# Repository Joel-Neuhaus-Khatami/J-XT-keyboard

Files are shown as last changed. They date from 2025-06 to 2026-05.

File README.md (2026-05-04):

# XT Keyboard Project

NOTE: The RP2040 based design is being replaced with an STM32 variety instead. The readme is thus out of date, however the case files are final
New pcb and firmware will be merged soon.

This repo is for all the files used in designing and manufacturing a mechanical keyboard that I made from scratch.
The keyboard itself is a modified XT layout, which was a very popular layout for 1980's keyboards.

The case is inspired by the IBM Model F77, Cherry G80-0418 and the modern NCR80.
Later angularity and side-bezel thickness was inspired by the Pravetz 16 from the Soviet Union and various NCR G80 varieties, for example the NCR G80-0478.

The PCB is designed Cherry style switch sockets meant for soldering,  all of which are south facing to avoid Cherry profile interference.
The layout is a mix of various layout types, such as the ISO left side 1.25u shift, split right shift, split backspace, which are not changeable.
It does however support stepped caps lock as well as a regular caps lock.
The final PCB iteration is designed with an STM32 chip and currently has only QMK firmware compatibility. This design is confirmed working (from the fact that this README is currently being authored with it).
The PCB was originally designed with using the ATMega32u4 first, then the RP2040, however none of these worked and should be discarded if found in the git history.
Due to the case dimensions, the main intended I/O for the keyboard is a 4-pin Molex Pico EZmate connector and a daughterboard,
in this instance the UDB (Unified Daughterboard) C4. For previous iterations, a full USB type C recepticle + ESD protection diode was added, but these were removed to reduce complexity and assembly time.

## 1. Layout

Capture2

The layout is a mix of the standard HHKB for the Alphanumerical section, XT-esque left side F-row and a 3x5 1U grid inspired by the IBM Model F-77
  
## 2. Schematics

Early visualization of switch matrix (This layout was changed tremendously due to later solutions for multiple layouts)
switch_matrix

Switch matrix translated to Kicad schematics


Full schematics of the board
bilde

Routed pcb
bilde
bilde
bilde

3D render (front)
bilde

3D render (back)
bilde

RP2040, Crystal and Debug pins
bilde

USB Type C Recepticle, ESD Protection Diode and 4-pin Molex Connector
bilde

## 3. Case

Top case w/ plate


Top and Bottom case side profile



Back view including slit for UDB implementation


Inside view of Top case, showing plate top mount + UDB implementation


Inside view of Bottom case


Bottom


## 4. Acknowledgements on PCB design

Given that this project is open source, the shortcomings of the designs and reflections should be acknowledged as its own separate section. The main issue design wise with the PCB is the the 100nF capacitor being on the top rather than the bottom of the PCB. There is no doubt that the capacitor needed to be much closer to RST, however it could have been implemented more elegantly, but this wasn't possible due to time constraints. Also, the board has little/no indicators or tools to perform debugging other than the available BOOT and RST buttons on the back. Indicator lights and available pins for the purposes of debugging would have been useful, and could present a very challenging debugging experience.

To be posted:
Manufactured PCBA and Aluminium case

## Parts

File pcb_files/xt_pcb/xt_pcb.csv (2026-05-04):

# | Reference | Qty | Value | Footprint | DNP
1 | C1, C3 | 2 | 1uF | Capacitor_SMD:C_0402_1005Metric
2 | C2, C5, C6, C7, C8, C9 | 6 | 100nF | Capacitor_SMD:C_0402_1005Metric
3 | C4 | 1 | 4.7uF | Capacitor_SMD:C_0402_1005Metric
4 | D1, D2, D3, D4, D5, D6, D7, D8, D9, D10, D11, D12, D13, D14, D15, D16, D17, D18, D19, D20, D21, D22, D23, D24, D25, D26, D27, D28, D29, D30, D31, D32, D33, D34, D35, D36, D37, D38, D39, D40, D41, D42, D43, D44, D45, D46, D47, D48, D49, D50, D51, D52, D53, D54, D55, D56, D57, D58, D59, D60, D61, D62, D63, D64, D65, D66, D67, D68, D69, D70, D71, D72, D73, D74, D75, D76, D77, D78, D79, D80, D81, D82, D83, D84, D85, D86 | 86 | D | Diode_SMD:D_SOD-123
5 | J1 | 1 | JST | Connector_Molex:Molex_Pico-EZmate_78171-0004_1x04-1MP_P1.20mm_Vertical
6 | R1 | 1 | 10k | Resistor_SMD:R_0402_1005Metric
7 | R2, R3 | 2 | 22Ω | Capacitor_SMD:C_0402_1005Metric
8 | SW1, SW2 | 2 | RST | Button_Switch_SMD:SW_SPST_SKQG_WithoutStem
9 | SW3, SW4, SW5, SW6, SW7, SW8, SW9, SW10, SW11, SW12, SW13, SW18, SW19, SW20, SW21, SW22, SW23, SW24, SW25, SW26, SW29, SW30, SW31, SW32, SW34, SW35, SW36, SW37, SW38, SW39, SW40, SW41, SW42, SW43, SW44, SW45, SW46, SW47, SW48, SW49, SW51, SW52, SW53, SW54, SW55, SW56, SW57, SW58, SW60, SW61, SW62, SW63, SW64, SW65, SW66, SW67, SW68, SW69, SW70, SW71, SW73, SW76, SW77, SW78, SW79, SW80, SW81, SW82, SW83, SW84, SW85, SW86, SW87, SW88, SW89, SW90, SW91 | 77 | SW_Push | PCM_Switch_Keyboard_Cherry_MX:SW_Cherry_MX_PCB_1.00u
10 | SW14, SW74 | 2 | SW_Push | PCM_Switch_Keyboard_Cherry_MX:SW_Cherry_MX_PCB_1.50u
11 | SW15 | 1 | SW_Push | PCM_Switch_Keyboard_Cherry_MX:SW_Cherry_MX_PCB_1.75u
12 | SW16, SW27, SW59 | 3 | SW_Push | PCM_Switch_Keyboard_Cherry_MX:SW_Cherry_MX_PCB_1.25u
13 | SW17, SW75 | 2 | SW_Push | PCM_Switch_Keyboard_Cherry_MX:SW_Cherry_MX_PCB_2.25u
14 | SW28 | 1 | SW_Push | PCM_Mounting_Keyboard_Stabilizer:Stabilizer_Cherry_MX_2.00u
15 | SW33 | 1 | SW_Push | PCM_Mounting_Keyboard_Stabilizer:Stabilizer_Cherry_MX_6.25u
16 | SW50 | 1 | SW_Push | PCM_Switch_Keyboard_Cherry_MX:SW_Cherry_MX_PCB_6.25u
17 | SW72 | 1 | SW_Push | PCM_Switch_Keyboard_Cherry_MX:SW_Cherry_MX_PCB_2.75u
18 | U1 | 1 | STM32F072C8Tx | Package_QFP:LQFP-48_7x7mm_P0.5mm
19 | U2 | 1 | XC6206PxxxMR-Regulator_Linear | Package_TO_SOT_SMD:SOT-23

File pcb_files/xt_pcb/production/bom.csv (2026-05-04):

Designator | Footprint | Quantity | Value | LCSC Part #
C1, C3 | 0402 | 2 | 1uF | C52923
C2 | 0603 | 1 | 100nF | C307331
C4 | 0402 | 1 | 4.7uF | C23733
C5, C6, C7, C8, C9 | 0402 | 5 | 100nF | C307331
D1, D10, D11, D12, D13, D14, D15, D16, D17, D18, D19, D2, D20, D21, D22, D23, D24, D25, D26, D27, D28, D29, D3, D30, D31, D32, D33, D34, D35, D36, D37, D38, D39, D4, D40, D41, D42, D43, D44, D45, D46, D47, D48, D49, D5, D50, D51, D52, D53, D54, D55, D56, D57, D58, D59, D6, D60, D61, D62, D63, D64, D65, D66, D67, D68, D69, D7, D70, D71, D72, D73, D74, D75, D76, D77, D78, D79, D8, D80, D81, D82, D83, D84, D85, D86, D9 | D_SOD-123 | 86 | D
J1 | Molex_Pico-EZmate_78171-0004_1x04-1MP_P1.20mm_Vertical | 1 | JST | C588524
R1 | 0402 | 1 | 10k | C25744
R2, R3 | 0402 | 2 | 22Ω | C25092
SW1, SW2 | SW_SPST_SKQG_WithoutStem | 2 | RST | C139779
SW10, SW11, SW12, SW13, SW18, SW19, SW20, SW21, SW22, SW23, SW24, SW25, SW26, SW29, SW3, SW30, SW31, SW32, SW34, SW35, SW36, SW37, SW38, SW39, SW4, SW40, SW41, SW42, SW43, SW44, SW45, SW46, SW47, SW48, SW49, SW5, SW51, SW52, SW53, SW54, SW55, SW56, SW57, SW58, SW6, SW60, SW61, SW62, SW63, SW64, SW65, SW66, SW67, SW68, SW69, SW7, SW70, SW71, SW73, SW76, SW77, SW78, SW79, SW8, SW80, SW81, SW82, SW83, SW84, SW85, SW86, SW87, SW88, SW89, SW9, SW90, SW91 | SW_Cherry_MX_PCB_1.00u | 77 | SW_Push
SW14, SW74 | SW_Cherry_MX_PCB_1.50u | 2 | SW_Push
SW15 | SW_Cherry_MX_PCB_1.75u | 1 | SW_Push
SW16, SW17, SW27, SW59 | SW_Cherry_MX_PCB_1.25u | 4 | SW_Push
SW28 | Stabilizer_Cherry_MX_2.00u | 1 | SW_Push
SW33 | Stabilizer_Cherry_MX_6.25u | 1 | SW_Push
SW50 | SW_Cherry_MX_PCB_6.25u | 1 | SW_Push
SW72 | SW_Cherry_MX_Plate_1.75u | 1 | SW_Push
SW75 | SW_Cherry_MX_PCB_2.25u | 1 | SW_Push
U1 | LQFP-48_7x7mm_P0.5mm | 1 | STM32F072C8Tx | C80488
U2 | SOT-23 | 1 | XC6206PxxxMR-Regulator_Linear | C5446

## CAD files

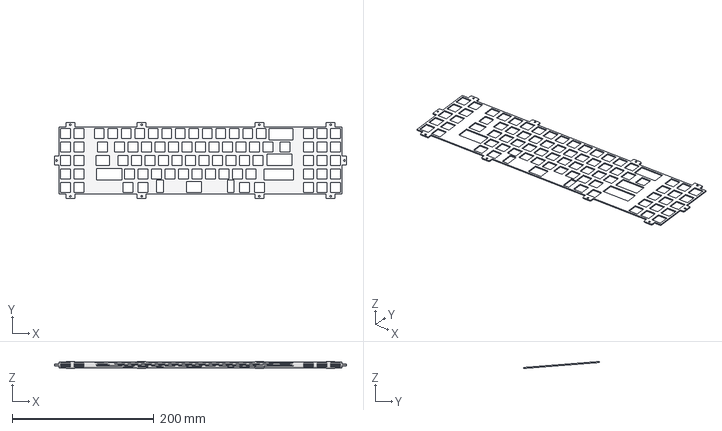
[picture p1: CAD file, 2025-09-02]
case_files/plate.step
412.0 x 107.1 x 9.91 mm

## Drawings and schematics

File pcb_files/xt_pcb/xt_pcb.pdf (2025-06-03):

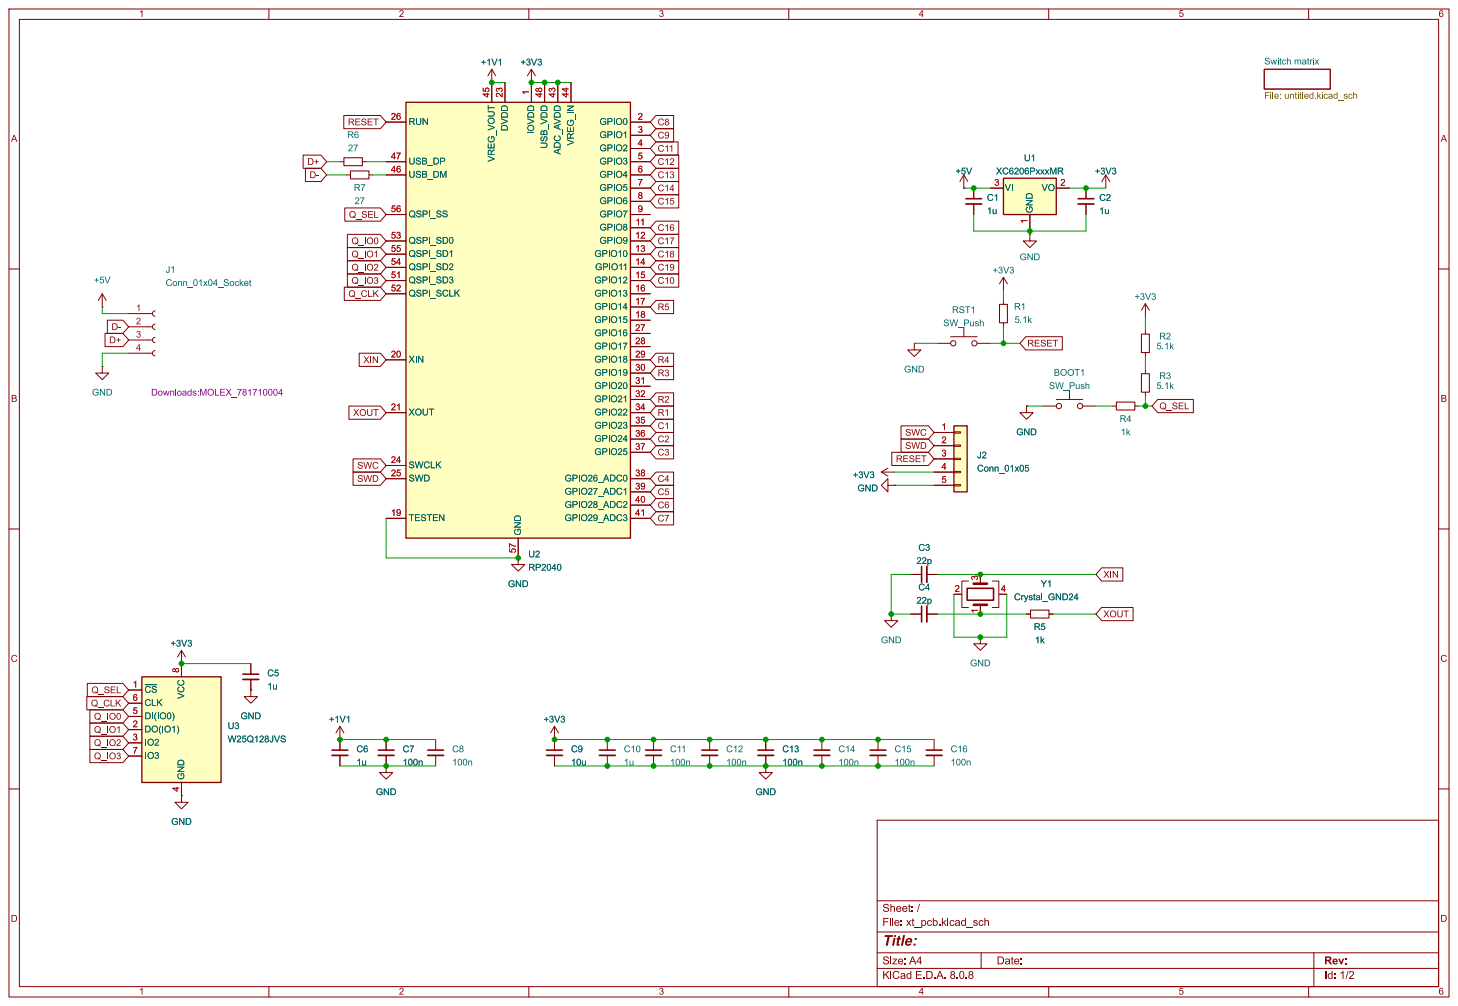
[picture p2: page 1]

Switch matrix File: untitled.kicad_sch +3V3 R2

Id: 1/2 Title: File: xt_pcb.kicad_sch Sheet: /

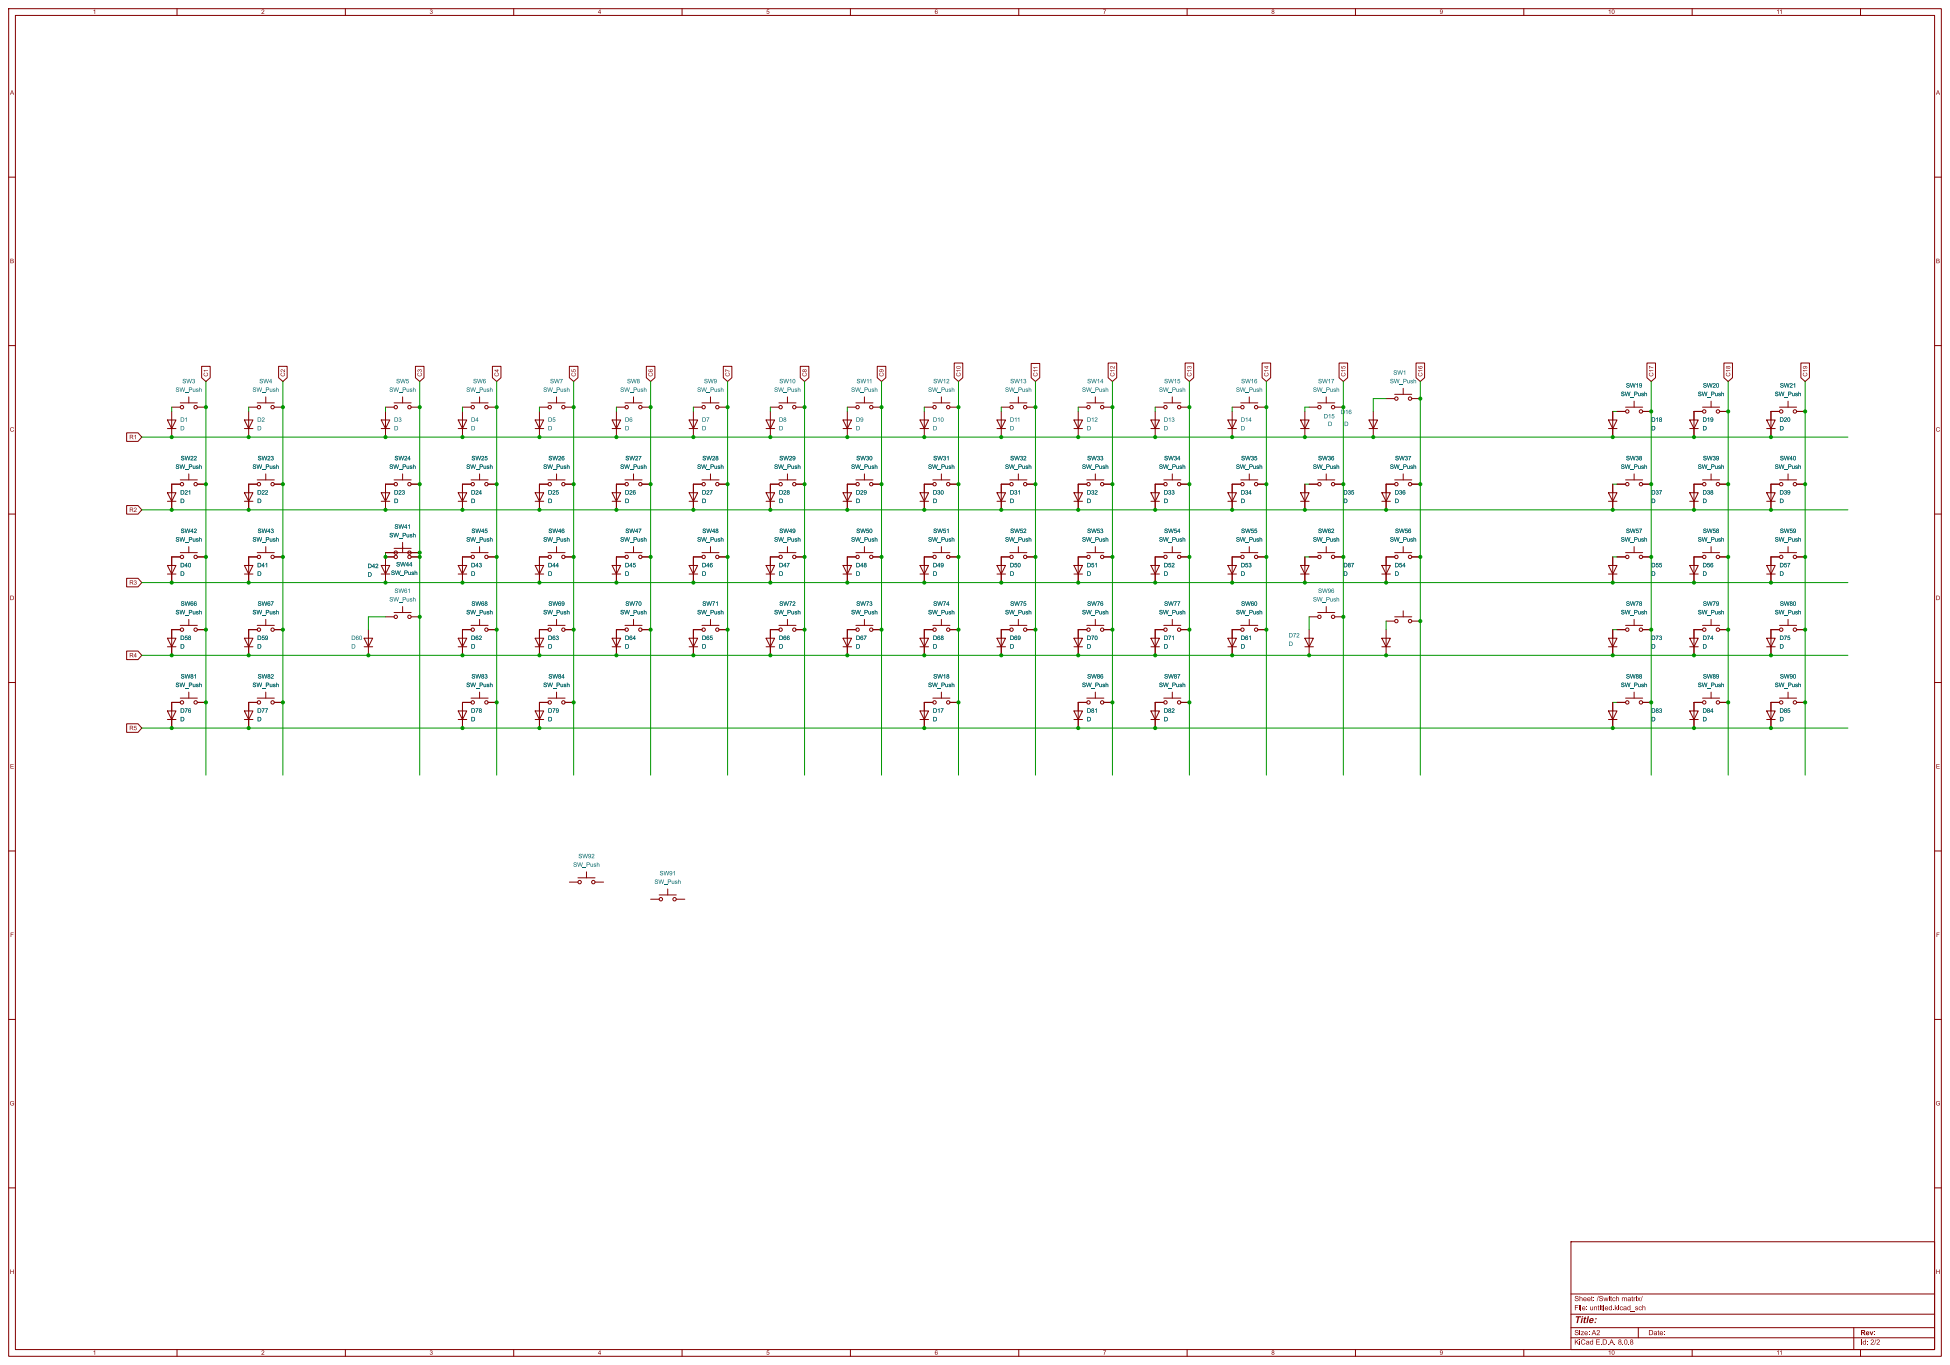
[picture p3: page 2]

Id: 2/2 Title: File: untitled.kicad_sch Sheet: /Switch matrix/

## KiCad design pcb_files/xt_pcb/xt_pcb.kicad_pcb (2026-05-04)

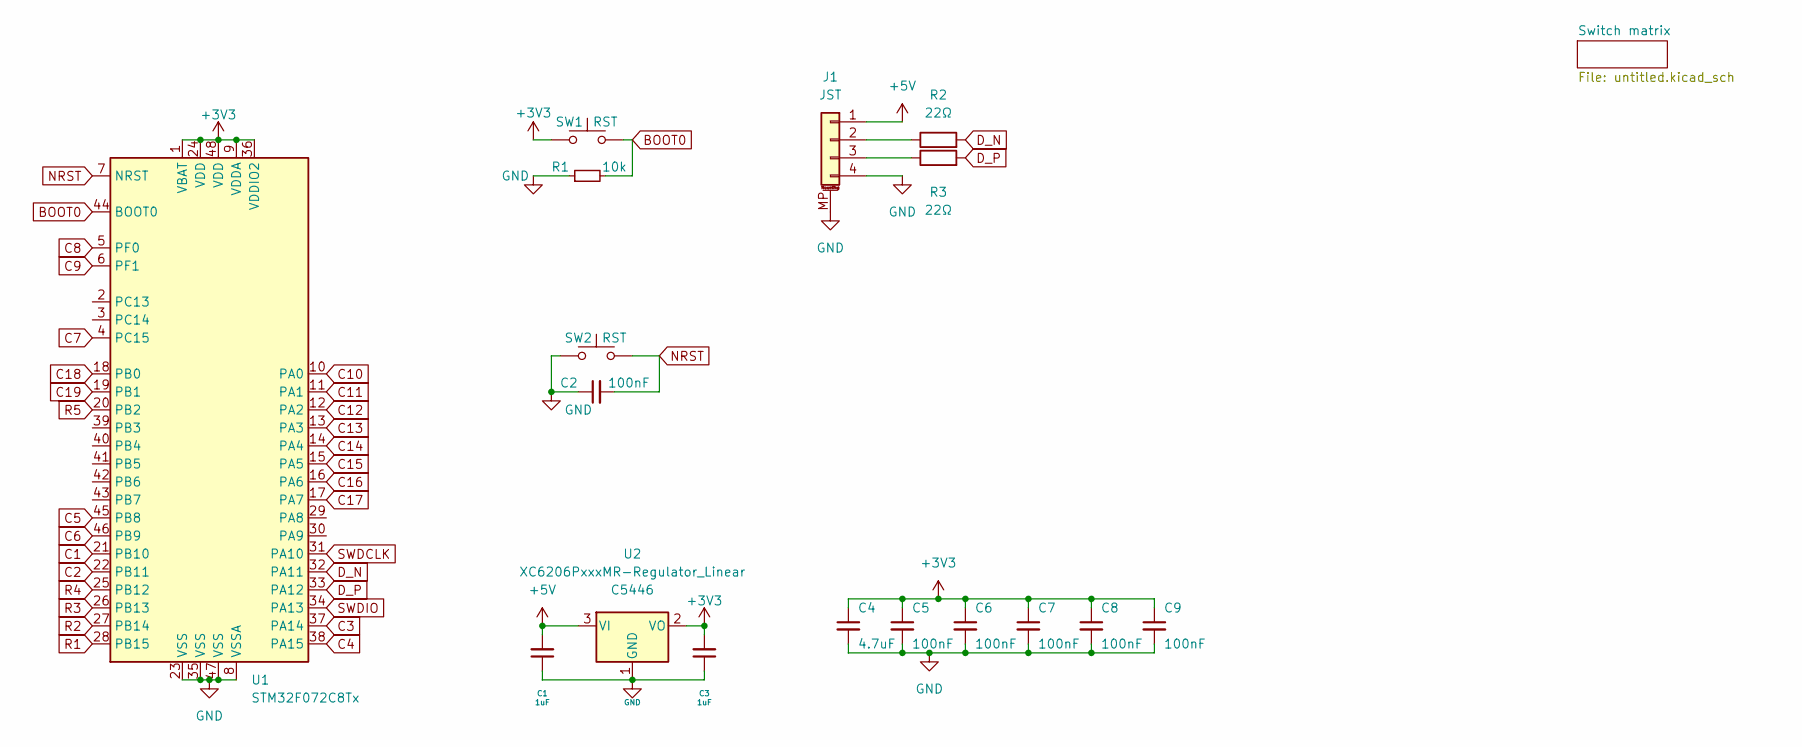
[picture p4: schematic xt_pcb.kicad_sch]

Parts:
C1, C3: 1uF; C_0402_1005Metric; LCSC C52923
C2: 100nF; C_0603_1608Metric_Pad1.08x0.95mm_HandSolder; LCSC C307331
C4: 4.7uF; C_0402_1005Metric; LCSC C23733
C5, C6, C7, C8, C9: 100nF; C_0402_1005Metric; LCSC C307331
J1: JST; Molex_Pico-EZmate_78171-0004_1x04-1MP_P1.20mm_Vertical; LCSC C588524
R1: 10k; R_0402_1005Metric; LCSC C25744
R2, R3: 22Ω; C_0402_1005Metric; LCSC C25092
SW1, SW2: RST; SW_SPST_SKQG_WithoutStem; LCSC C139779
U1: STM32F072C8Tx; LQFP-48_7x7mm_P0.5mm; LCSC C80488
U2: XC6206PxxxMR-Regulator_Linear; SOT-23; LCSC C5446

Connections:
+3V3: C3.2, C4.1, C5.1, C6.1, C7.1, C8.1, C9.1, SW1.1, U1.1 (VBAT), U1.9 (VDDA), U1.24 (VDD), U1.36 (VDDIO2), U1.48 (VDD), U2.2 (VO)
+5V: C1.2, J1.1, U2.3 (VI)
BOOT0: R1.2, SW1.2, U1.44 (BOOT0)
C1: U1.21 (PB10); also elsewhere on the board
C2: U1.22 (PB11); also elsewhere on the board
C3: U1.37 (PA14); also elsewhere on the board
C4: U1.38 (PA15); also elsewhere on the board
C5: U1.45 (PB8); also elsewhere on the board
C6: U1.46 (PB9); also elsewhere on the board
C7: U1.4 (PC15); also elsewhere on the board
C8: U1.5 (PF0); also elsewhere on the board
C9: U1.6 (PF1); also elsewhere on the board
C10: U1.10 (PA0); also elsewhere on the board
C11: U1.11 (PA1); also elsewhere on the board
C12: U1.12 (PA2); also elsewhere on the board
C13: U1.13 (PA3); also elsewhere on the board
C14: U1.14 (PA4); also elsewhere on the board
C15: U1.15 (PA5); also elsewhere on the board
C16: U1.16 (PA6); also elsewhere on the board
C17: U1.17 (PA7); also elsewhere on the board
C18: U1.18 (PB0); also elsewhere on the board
C19: U1.19 (PB1); also elsewhere on the board
D_N: R2.2, U1.32 (PA11)
D_P: R3.2, U1.33 (PA12)
GND: C1.1, C2.1, C3.1, C4.2, C5.2, C6.2, C7.2, C8.2, C9.2, J1.4, J1.MP (MountPin), R1.1, SW2.1, U1.8 (VSSA), U1.23 (VSS), U1.35 (VSS), U1.47 (VSS), U2.1 (GND)
NRST: C2.2, SW2.2, U1.7 (NRST)
unnamed: J1.2, R2.1
unnamed: J1.3, R3.1
R1: U1.28 (PB15); also elsewhere on the board
R2: U1.27 (PB14); also elsewhere on the board
R3: U1.26 (PB13); also elsewhere on the board
R4: U1.25 (PB12); also elsewhere on the board
R5: U1.20 (PB2); also elsewhere on the board
SWDCLK: U1.31 (PA10)
SWDIO: U1.34 (PA13)

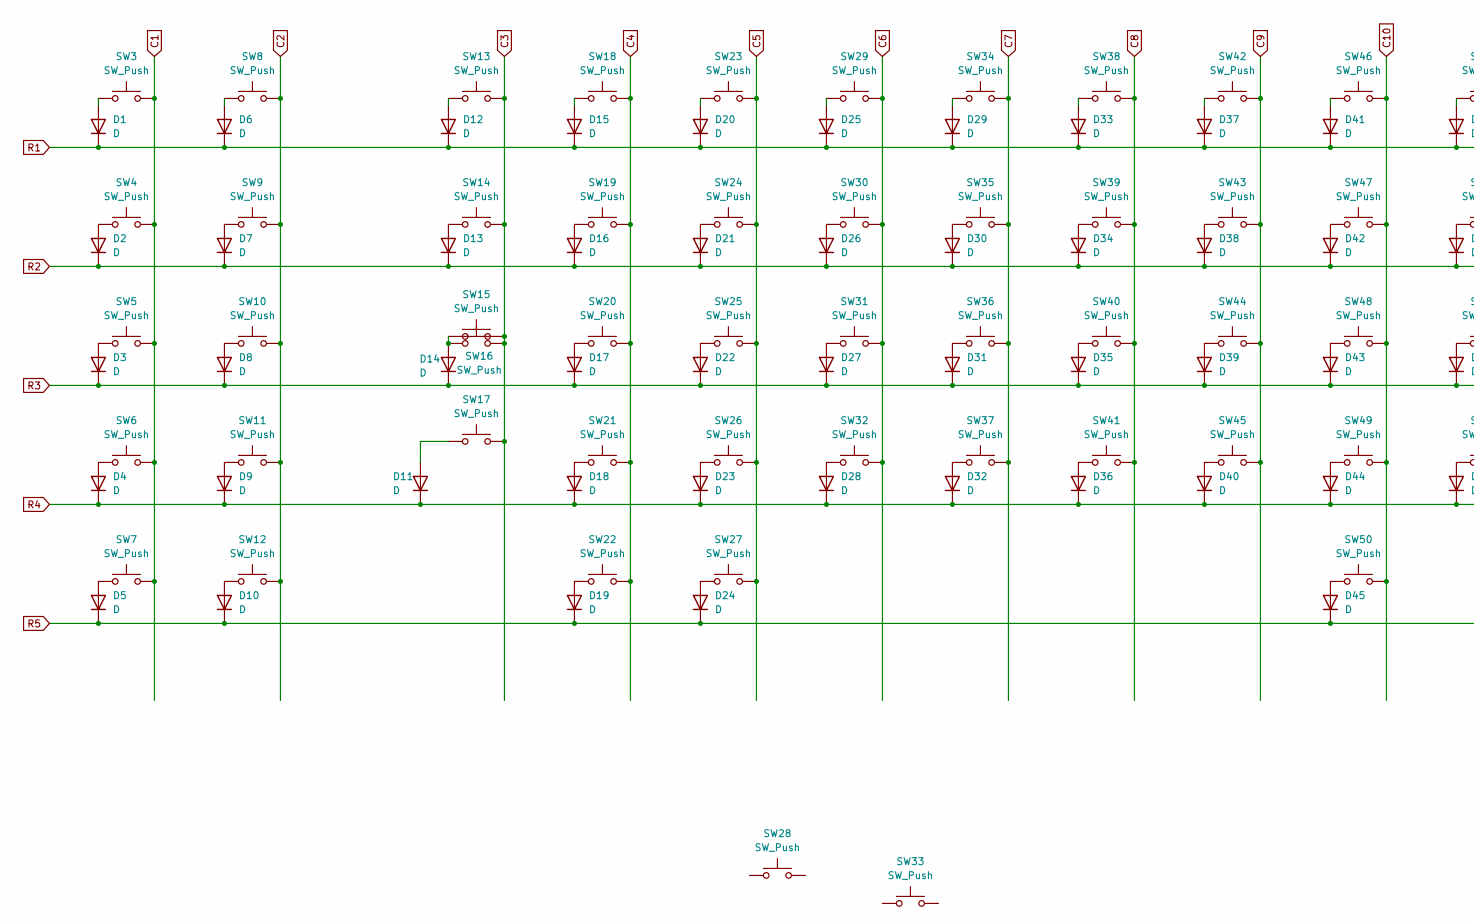
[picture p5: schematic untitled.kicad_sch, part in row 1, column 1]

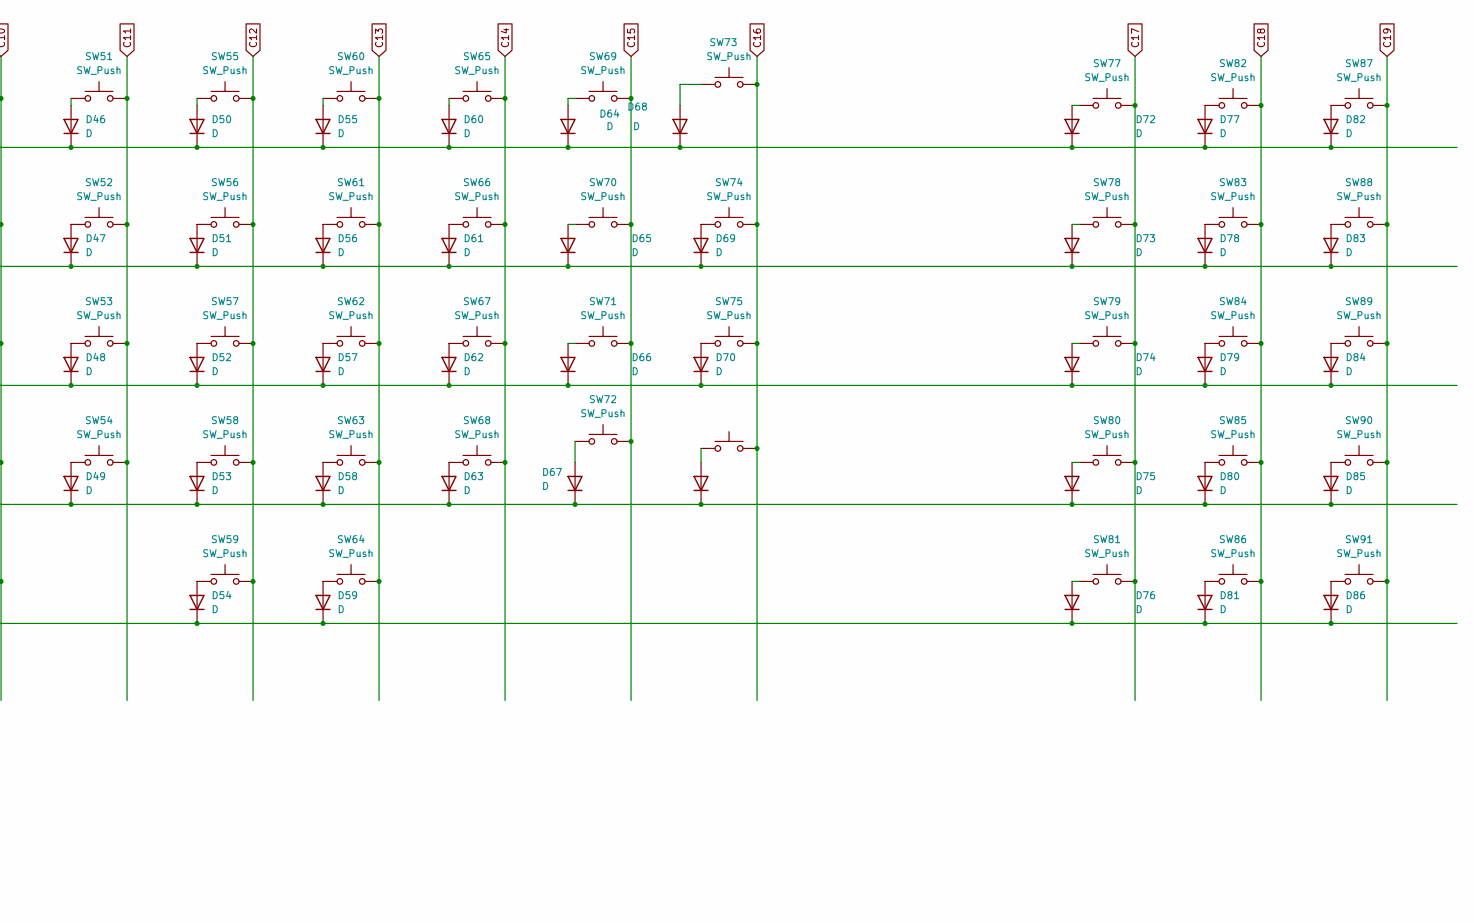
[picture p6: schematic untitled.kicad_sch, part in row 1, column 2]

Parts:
D1, D2, D3, D4, D5, D6, D7, D8, D9, D10, D11, D12, D13, D14, D15, D16, D17, D18, D19, D20, D21, D22, D23, D24, D25, D26, D27, D28, D29, D30, D31, D32, D33, D34, D35, D36, D37, D38, D39, D40, D41, D42, D43, D44, D45, D46, D47, D48, D49, D50, D51, D52, D53, D54, D55, D56, D57, D58, D59, D60, D61, D62, D63, D64, D65, D66, D67, D68, D69, D70, D71, D72, D73, D74, D75, D76, D77, D78, D79, D80, D81, D82, D83, D84, D85, D86: D; D_SOD-123
SW3, SW4, SW5, SW6, SW7, SW8, SW9, SW10, SW11, SW12, SW13, SW18, SW19, SW20, SW21, SW22, SW23, SW24, SW25, SW26, SW29, SW30, SW31, SW32, SW34, SW35, SW36, SW37, SW38, SW39, SW40, SW41, SW42, SW43, SW44, SW45, SW46, SW47, SW48, SW49, SW51, SW52, SW53, SW54, SW55, SW56, SW57, SW58, SW60, SW61, SW62, SW63, SW64, SW65, SW66, SW67, SW68, SW69, SW70, SW71, SW73, SW76, SW77, SW78, SW79, SW80, SW81, SW82, SW83, SW84, SW85, SW86, SW87, SW88, SW89, SW90, SW91: SW_Push; SW_Cherry_MX_PCB_1.00u
SW14, SW74: SW_Push; SW_Cherry_MX_PCB_1.50u
SW15: SW_Push; SW_Cherry_MX_PCB_1.75u
SW16, SW17, SW27, SW59: SW_Push; SW_Cherry_MX_PCB_1.25u
SW28: SW_Push; Stabilizer_Cherry_MX_2.00u
SW33: SW_Push; Stabilizer_Cherry_MX_6.25u
SW50: SW_Push; SW_Cherry_MX_PCB_6.25u
SW72: SW_Push; SW_Cherry_MX_Plate_1.75u
SW75: SW_Push; SW_Cherry_MX_PCB_2.25u

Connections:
C1: SW3.2, SW4.2, SW5.2, SW6.2, SW7.2; also elsewhere on the board
C2: SW8.2, SW9.2, SW10.2, SW11.2, SW12.2; also elsewhere on the board
C3: SW13.2, SW14.2, SW15.2, SW16.2, SW17.2; also elsewhere on the board
C4: SW18.2, SW19.2, SW20.2, SW21.2, SW22.2; also elsewhere on the board
C5: SW23.2, SW24.2, SW25.2, SW26.2, SW27.2; also elsewhere on the board
C6: SW29.2, SW30.2, SW31.2, SW32.2; also elsewhere on the board
C7: SW34.2, SW35.2, SW36.2, SW37.2; also elsewhere on the board
C8: SW38.2, SW39.2, SW40.2, SW41.2; also elsewhere on the board
C9: SW42.2, SW43.2, SW44.2, SW45.2; also elsewhere on the board
C10: SW46.2, SW47.2, SW48.2, SW49.2, SW50.2; also elsewhere on the board
C11: SW51.2, SW52.2, SW53.2, SW54.2; also elsewhere on the board
C12: SW55.2, SW56.2, SW57.2, SW58.2, SW59.2; also elsewhere on the board
C13: SW60.2, SW61.2, SW62.2, SW63.2, SW64.2; also elsewhere on the board
C14: SW65.2, SW66.2, SW67.2, SW68.2; also elsewhere on the board
C15: SW69.2, SW70.2, SW71.2, SW72.2; also elsewhere on the board
C16: SW73.2, SW74.2, SW75.2, SW76.2; also elsewhere on the board
C17: SW77.2, SW78.2, SW79.2, SW80.2, SW81.2; also elsewhere on the board
C18: SW82.2, SW83.2, SW84.2, SW85.2, SW86.2; also elsewhere on the board
C19: SW87.2, SW88.2, SW89.2, SW90.2, SW91.2; also elsewhere on the board
unnamed: D1.2 (A), SW3.1
unnamed: D2.2 (A), SW4.1
unnamed: D3.2 (A), SW5.1
unnamed: D4.2 (A), SW6.1
unnamed: D5.2 (A), SW7.1
unnamed: D6.2 (A), SW8.1
unnamed: D7.2 (A), SW9.1
unnamed: D8.2 (A), SW10.1
unnamed: D9.2 (A), SW11.1
unnamed: D10.2 (A), SW12.1
unnamed: D11.2 (A), SW17.1
unnamed: D12.2 (A), SW13.1
unnamed: D13.2 (A), SW14.1
unnamed: D14.2 (A), SW15.1, SW16.1
unnamed: D15.2 (A), SW18.1
unnamed: D16.2 (A), SW19.1
unnamed: D17.2 (A), SW20.1
unnamed: D18.2 (A), SW21.1
unnamed: D19.2 (A), SW22.1
unnamed: D20.2 (A), SW23.1
unnamed: D21.2 (A), SW24.1
unnamed: D22.2 (A), SW25.1
unnamed: D23.2 (A), SW26.1
unnamed: D24.2 (A), SW27.1
unnamed: D25.2 (A), SW29.1
unnamed: D26.2 (A), SW30.1
unnamed: D27.2 (A), SW31.1
unnamed: D28.2 (A), SW32.1
unnamed: D29.2 (A), SW34.1
unnamed: D30.2 (A), SW35.1
unnamed: D31.2 (A), SW36.1
unnamed: D32.2 (A), SW37.1
unnamed: D33.2 (A), SW38.1
unnamed: D34.2 (A), SW39.1
unnamed: D35.2 (A), SW40.1
unnamed: D36.2 (A), SW41.1
unnamed: D37.2 (A), SW42.1
unnamed: D38.2 (A), SW43.1
unnamed: D39.2 (A), SW44.1
unnamed: D40.2 (A), SW45.1
unnamed: D41.2 (A), SW46.1
unnamed: D42.2 (A), SW47.1
unnamed: D43.2 (A), SW48.1
unnamed: D44.2 (A), SW49.1
unnamed: D45.2 (A), SW50.1
unnamed: D46.2 (A), SW51.1
unnamed: D47.2 (A), SW52.1
unnamed: D48.2 (A), SW53.1
unnamed: D49.2 (A), SW54.1
unnamed: D50.2 (A), SW55.1
unnamed: D51.2 (A), SW56.1
unnamed: D52.2 (A), SW57.1
unnamed: D53.2 (A), SW58.1
unnamed: D54.2 (A), SW59.1
unnamed: D55.2 (A), SW60.1
unnamed: D56.2 (A), SW61.1
unnamed: D57.2 (A), SW62.1
unnamed: D58.2 (A), SW63.1
unnamed: D59.2 (A), SW64.1
unnamed: D60.2 (A), SW65.1
unnamed: D61.2 (A), SW66.1
unnamed: D62.2 (A), SW67.1
unnamed: D63.2 (A), SW68.1
unnamed: D64.2 (A), SW69.1
unnamed: D65.2 (A), SW70.1
unnamed: D66.2 (A), SW71.1
unnamed: D67.2 (A), SW72.1
unnamed: D68.2 (A), SW73.1
unnamed: D69.2 (A), SW74.1
unnamed: D70.2 (A), SW75.1
unnamed: D71.2 (A), SW76.1
unnamed: D72.2 (A), SW77.1
unnamed: D73.2 (A), SW78.1
unnamed: D74.2 (A), SW79.1
unnamed: D75.2 (A), SW80.1
unnamed: D76.2 (A), SW81.1
unnamed: D77.2 (A), SW82.1
unnamed: D78.2 (A), SW83.1
unnamed: D79.2 (A), SW84.1
unnamed: D80.2 (A), SW85.1
unnamed: D81.2 (A), SW86.1
unnamed: D82.2 (A), SW87.1
unnamed: D83.2 (A), SW88.1
unnamed: D84.2 (A), SW89.1
unnamed: D85.2 (A), SW90.1
unnamed: D86.2 (A), SW91.1
R1: D1.1 (K), D6.1 (K), D12.1 (K), D15.1 (K), D20.1 (K), D25.1 (K), D29.1 (K), D33.1 (K), D37.1 (K), D41.1 (K), D46.1 (K), D50.1 (K), D55.1 (K), D60.1 (K), D64.1 (K), D68.1 (K), D72.1 (K), D77.1 (K), D82.1 (K); also elsewhere on the board
R2: D2.1 (K), D7.1 (K), D13.1 (K), D16.1 (K), D21.1 (K), D26.1 (K), D30.1 (K), D34.1 (K), D38.1 (K), D42.1 (K), D47.1 (K), D51.1 (K), D56.1 (K), D61.1 (K), D65.1 (K), D69.1 (K), D73.1 (K), D78.1 (K), D83.1 (K); also elsewhere on the board
R3: D3.1 (K), D8.1 (K), D14.1 (K), D17.1 (K), D22.1 (K), D27.1 (K), D31.1 (K), D35.1 (K), D39.1 (K), D43.1 (K), D48.1 (K), D52.1 (K), D57.1 (K), D62.1 (K), D66.1 (K), D70.1 (K), D74.1 (K), D79.1 (K), D84.1 (K); also elsewhere on the board
R4: D4.1 (K), D9.1 (K), D11.1 (K), D18.1 (K), D23.1 (K), D28.1 (K), D32.1 (K), D36.1 (K), D40.1 (K), D44.1 (K), D49.1 (K), D53.1 (K), D58.1 (K), D63.1 (K), D67.1 (K), D71.1 (K), D75.1 (K), D80.1 (K), D85.1 (K); also elsewhere on the board
R5: D5.1 (K), D10.1 (K), D19.1 (K), D24.1 (K), D45.1 (K), D54.1 (K), D59.1 (K), D76.1 (K), D81.1 (K), D86.1 (K); also elsewhere on the board

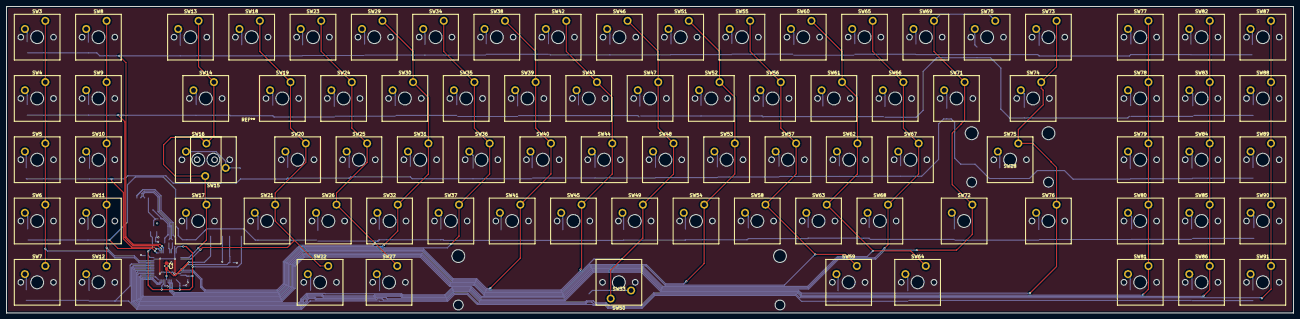
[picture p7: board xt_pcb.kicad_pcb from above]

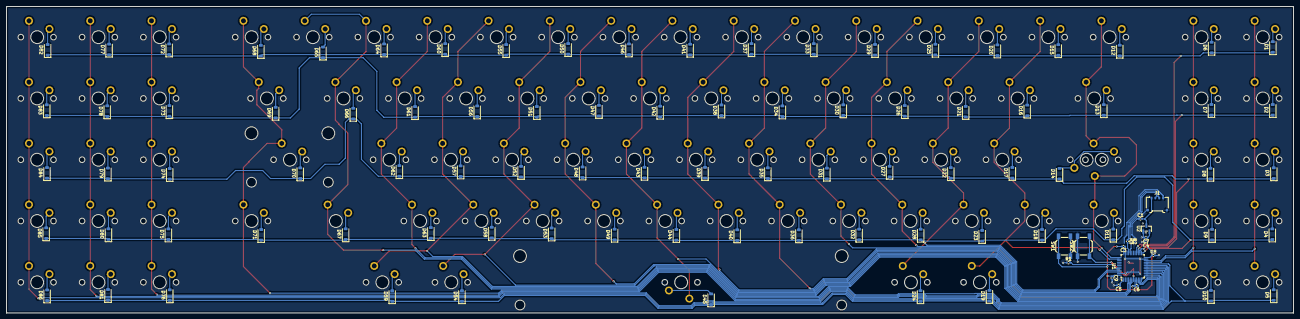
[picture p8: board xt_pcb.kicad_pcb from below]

Board: 2 copper layers, 400.1 x 95.2 mm, 192 parts (102 on the bottom side), 119 nets.

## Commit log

2025-06-03 connected connected the switch matrix to gpio
    [untitled.kicad_sch, xt_pcb.kicad_pcb, xt_pcb.kicad_sch]
2025-06-03 tracing adjustments
    [xt_pcb.kicad_pcb]
2025-06-03 drc debugging
    [xt_pcb.kicad_pcb]
2025-06-03 new 5v
    [xt_pcb.kicad_pcb]
2025-06-03 additional 5v + differential adjustments
2025-06-04 prod files
    [bom.csv, designators.csv, positions.csv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]
2025-07-25 routing algorithm used
    [freerouting.dsn, temp-freerouting.dsn, untitled.kicad_sch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]
2025-07-27 routing halluc. removed + usb c added
    [xt_pcb.kicad_pcb, xt_pcb.kicad_sch]
2025-07-27 esd diode
    [xt_pcb.kicad_pcb, xt_pcb.kicad_pcb_bom.csv, xt_pcb.kicad_pcb_positions.csv]
2025-07-28 debugging + prod files
    [bom.csv, designators.csv, positions.csv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]
2025-08-03 removed all 90 deg
    [xt_pcb.kicad_pcb]
2025-08-07 90 deg removed
    [xt_pcb.kicad_pcb]
2025-08-12 vias removed
    [xt_pcb.kicad_pcb, xt_pcb.kicad_sch]
2025-08-13 cleaned up vias
    [xt_pcb.kicad_pcb, xt_pcb.kicad_sch]
2025-08-13 new prod files
    [positions.csv, xt_pcb.kicad_pcb]
2025-08-13 removed not needed files
    [xt_pcb-B_Cu.gbr, xt_pcb-B_Mask.gbr, xt_pcb-B_Paste.gbr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]
2025-08-13 gerbers + new prod
    [xt_pcb-B_Cu.gbr, xt_pcb-B_Mask.gbr, xt_pcb-B_Paste.gbr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]
2025-08-13 (kicad_pcb (version 20241229) (generator "pcbnew") (generator_version "9.0") (layers (0 "F.Cu" signal) (2 "B.Cu" signal) (9 "F.Adhes" user "F.Adhesive") (11 "B.Adhes" user "B.Adhesive") (13 "F.Paste"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
2025-08-14 correct drill files plotted
    [xt_pcb-B_Cu.gbr, xt_pcb-B_Mask.gbr, xt_pcb-B_Paste.gbr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]
2025-08-14 gerber zip
2025-08-14 new molex footprint
    [bom.csv, positions.csv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]
2025-08-14 rmvd uneeded prod files
    [xt_pcb-B_Cu.gbr, xt_pcb-B_Mask.gbr, xt_pcb-B_Paste.gbr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]
2025-08-15 small sch tweaks
    [xt_pcb.kicad_pcb, xt_pcb.kicad_sch]
2025-08-23 firmware tweaks
    [xt_pcb.kicad_pcb]
2025-08-23 pcb tweaks
    [xt_pcb.kicad_pcb]
2025-08-24 firmware + function layering
    [xt_pcb.kicad_pcb]
2025-09-02 small plate tweal
    [plate.step]
2025-09-28 fix: removed usb type c
    [xt_pcb.kicad_pcb, xt_pcb.kicad_sch]
2025-11-28 feat: new stm32 based board in progress
    [untitled.kicad_sch, xt_pcb.kicad_pcb, xt_pcb.kicad_sch]
2025-12-20 feat: all mx sockets footprints changed
    [untitled.kicad_sch, xt_pcb.kicad_pcb]
2025-12-20 feat: added gnd fill
    [xt_pcb.kicad_pcb]
2025-12-21 feat: acheron conncectors for molex added
    [xt_pcb.kicad_pcb]
2025-12-21 feat: new molex connector
    [xt_pcb.kicad_pcb]
2026-01-03 feat: drc fixes
    [xt_pcb.kicad_pcb]
2026-04-06 0603 handsolder
    [bom.csv, positions.csv, xt_pcb.kicad_pcb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]
2026-04-06 allignment fix
    [xt_pcb.kicad_pcb]
2026-04-06 new footprint
    [bom.csv, positions.csv, untitled.kicad_sch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]
2026-04-17 updated lcsc information
    [bom.csv, xt_pcb.kicad_pcb, xt_pcb.kicad_sch]
